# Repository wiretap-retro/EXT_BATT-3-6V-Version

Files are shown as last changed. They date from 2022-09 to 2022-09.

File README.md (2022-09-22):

# EXT_BATT 3-6V Version
A battery supply for retro motherboards with an EXT_BATT header.

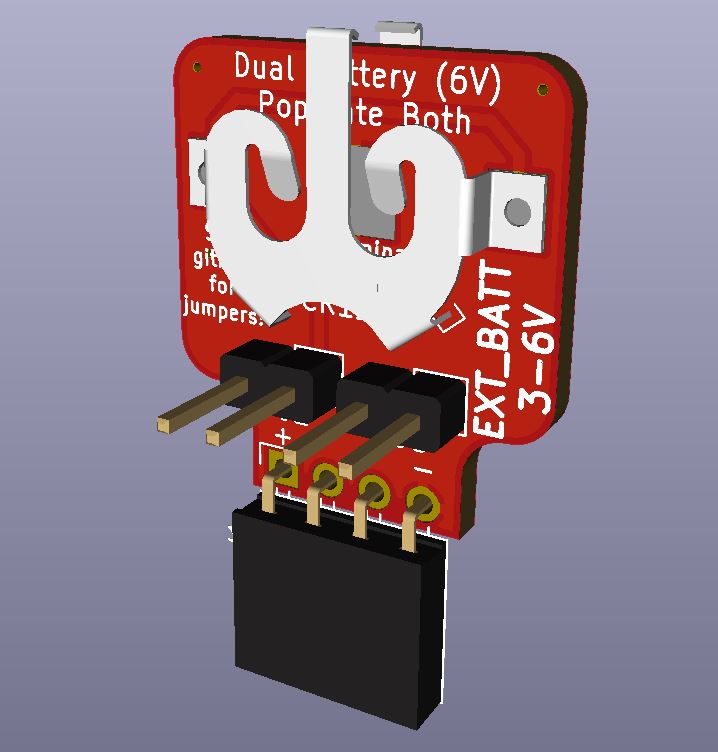
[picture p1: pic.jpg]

\
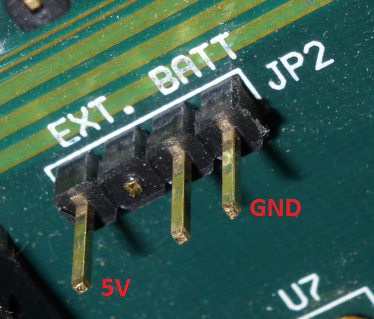
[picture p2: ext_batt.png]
mobo

\
^--photo from minuszerodegrees showing EXT_BATT header

## Info
I have quite a few 386 and 486 motherboards that have an EXT_BATT header, but I've removed the rechargable Varta. This PCB project is aimed at using the EXT_BATT header to provide a solution to keep your CMOS settings saved and RTC ticking. The MAX40200 chip provides for "ideal diode" functionality with less than a 43mV drop in voltage. It also prevents a charge circuit from trying to charge the CR1220 type batteries if the motherboard happens to have a charge circuit on the EXT_BATT header. (rare occurences) I prefer this board because the batteries are cheap, last a long time, and the EXT_BATT header is usually in an easier spot to get to than where the Varta battery is crammed on most boards. Regardless, check the batteries every few years.

## BOM
* This circuit board, ordered from your fabricator of choice. (JLCPCB, PCBway, OSH Park, etc.)
* Maxim MAX40200AUK+T Ideal Diode
* 2x Keystone Electronics 2894 battery holders
* 1x04 2.54mm pitch right angle pin socket, or 1x04 2.54mm pitch straight pin socket, or 1x04 2.54mm male pin headers (see below for mounting orientations)
* (2) 1x02 2.54mm pitch straight pin headers
* (1) 1x02 2.54mm pitch jumper
* 1-2x CR1220 batteries

## Jumper Settings

| J2  | J3 | Result |
| --- | --- | --- |
| SHORT | OPEN  | 6V |
| OPEN  | SHORT | 3V |
| SHORT | SHORT | Smoke |
| OPEN  | OPEN  | Nothing |

For 3V, populate the rear battery only. For 6V, populate both batteries. The negative battery terminal faces the PCB.
\
\
3V may work for your board, as there are many people that report a single 3V lithium cell is able to power their RTC. Of course, it depends on the minimum input voltage rating for the RTC chip. For 6V, please check your motherboard manual first to see if it will accept a voltage at that level.

## Installation
Set the jumper and plug the completed board into the EXT_BATT header. Several motherboards also use an INTERNAL/EXTERNAL jumper to select between the factory installed battery and the EXT_BATT header.
\
\
Mounting orientations:
* Vertical - this PCB sits about 32mm tall when installed vertically. 
* Horizontal - may be possible depending on your board's EXT_BATT header location/orientation and other nearby components.
* Remote - use pin header extension wires to connect to the EXT_BATT header and put the PCB somewhere else in the case.

## Other
Reference material for retro motherboard batteries: http://minuszerodegrees.net/battery/cmos/vintage_motherboard_batteries.htm
\
This project is open source, feel free to do what you want with it.

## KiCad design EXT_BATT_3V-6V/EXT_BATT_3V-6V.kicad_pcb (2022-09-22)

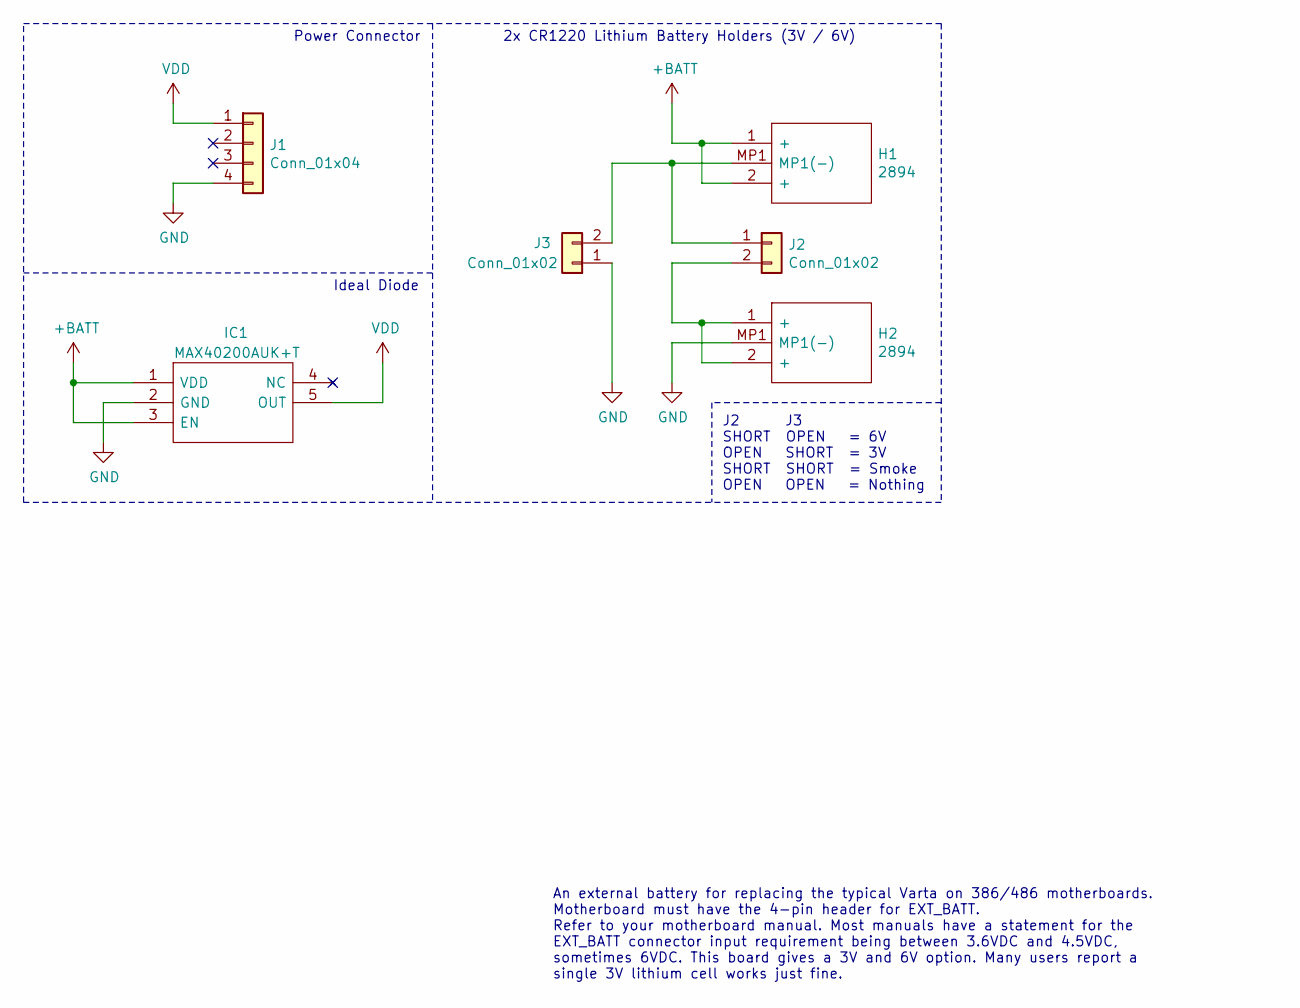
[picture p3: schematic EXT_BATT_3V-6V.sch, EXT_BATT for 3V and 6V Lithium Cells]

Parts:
H1, H2: 2894; Mouser Part Number 534-2894
IC1: MAX40200AUK+T; SOT95P280X145-5N; Mouser Part Number 700-MAX40200AUK+T
J1: Conn_01x04; PinSocket_1x04_P2.54mm_Horizontal
J2, J3: Conn_01x02; PinHeader_1x02_P2.54mm_Vertical

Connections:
+BATT: H1.1 (+), H1.2 (+), IC1.1 (VDD), IC1.3 (EN)
GND: H2.MP1 (MP1(-)), IC1.2 (GND), J1.4, J3.1
unnamed: H1.MP1 (MP1(-)), J2.1, J3.2
unnamed: H2.1 (+), H2.2 (+), J2.2
VDD: IC1.5 (OUT), J1.1

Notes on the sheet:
J2 J3 SHORT OPEN = 6V OPEN SHORT = 3V SHORT SHORT = Smoke OPEN OPEN = Nothing
Power Connector
Ideal Diode
2x CR1220 Lithium Battery Holders (3V / 6V)
An external battery for replacing the typical Varta on 386/486 motherboards. Motherboard must have the 4-pin header for EXT_BATT. Refer to your motherboard manual. Most manuals have a statement for the EXT_BATT connector input requirement being between 3.6VDC and 4.5VDC, sometimes 6VDC. This board 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

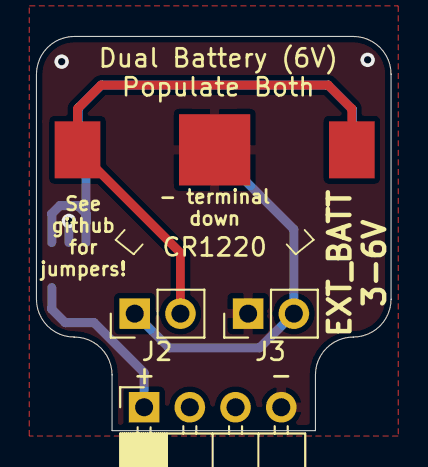
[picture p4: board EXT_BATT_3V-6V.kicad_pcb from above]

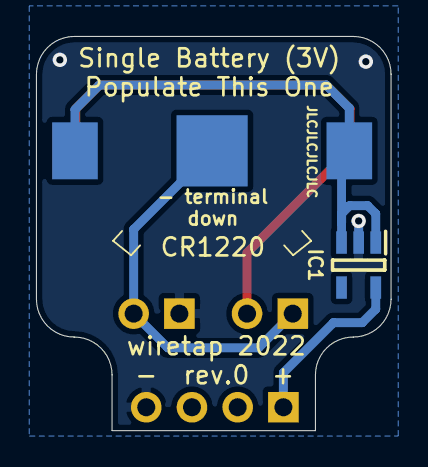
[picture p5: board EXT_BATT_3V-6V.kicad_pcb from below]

Board: 2 copper layers, 19.7 x 21.9 mm, 6 parts (2 on the bottom side), 5 nets.
